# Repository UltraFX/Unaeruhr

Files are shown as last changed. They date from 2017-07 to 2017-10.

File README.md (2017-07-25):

# Unaeruhr
Code and Layout for my unary clock

The unary clock is inspired by the clock on the "Rheinturm" in Düsseldorf, Germany. 

It's three lines with each tens (10-50) and ones (1-9) to display hours, minutes and seconds.
With a button, the display can be switched to show the date (month and day).
Another button can control the time

Later, DCF77 will be added to update the time automatically.

Still Work in Progress!!

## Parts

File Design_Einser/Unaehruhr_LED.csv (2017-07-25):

ID | Bezeichner | Gehäuse | Stückzahl | Bezeichnung | Anbieter und Ref.
1 | C1 | C_0805 | 1 | 100n
2 | D1,D2,D3,D4,D5,D6,D7,D8,D9 | LED_D5.0mm-4 | 9 | LED_RCBG
3 | P1 | Pin_Header_Straight_2x07_Pitch2.54mm | 1 | INPUT
4 | P2 | Pin_Header_Straight_2x07_Pitch2.54mm | 1 | OUTPUT
5 | Q1,Q4,Q7 | SOT-23 | 3 | Q_PNP_BEC
6 | Q2,Q3,Q5,Q6,Q8,Q9,Q10,Q11,Q12 | SOT-23 | 9 | BC849
7 | R1,R2,R3,R5,R7,R8,R9,R11,R12,R13,R14,R15 | R_0805 | 12 | 10k
8 | R4,R6,R10 | R_0805 | 3 | 68
9 | U1 | SOIC-16_3.9x9.9mm_Pitch1.27mm | 1 | 74HC595
10 | REF**,REF**,REF**,REF**,REF** | 1pin | 5 | 1pin

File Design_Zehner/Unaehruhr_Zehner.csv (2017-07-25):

ID | Bezeichner | Gehäuse | Stückzahl | Bezeichnung | Anbieter und Ref.
1 | REF**,REF**,REF**,REF** | 1pin | 4 | 1pin
2 | REF**,REF**,REF**,REF**,REF**,REF**,REF**,REF**,REF**,REF**,REF**,REF**,REF** | VIA-0.3mm | 13 | VIA-0.3mm
3 | P1 | Pin_Header_Straight_2x07_Pitch2.54mm | 1 | INPUT
4 | C1 | C_0805 | 1 | 100n
5 | D1,D2,D3,D4,D5 | LED_D5.0mm-4 | 5 | LED_RCBG
6 | P2 | Pin_Header_Straight_2x07_Pitch2.54mm | 1 | OUTPUT
7 | Q1,Q4,Q7 | SOT-23 | 3 | Q_PNP_BEC
8 | Q2,Q3,Q5,Q6,Q8 | SOT-23 | 5 | BC849
9 | R1,R2,R3,R5,R7,R8,R9,R11 | R_0805 | 8 | 10k
10 | R4,R6,R10 | R_0805 | 3 | 68
11 | U1 | SOIC-16_3.9x9.9mm_Pitch1.27mm | 1 | 74HC595

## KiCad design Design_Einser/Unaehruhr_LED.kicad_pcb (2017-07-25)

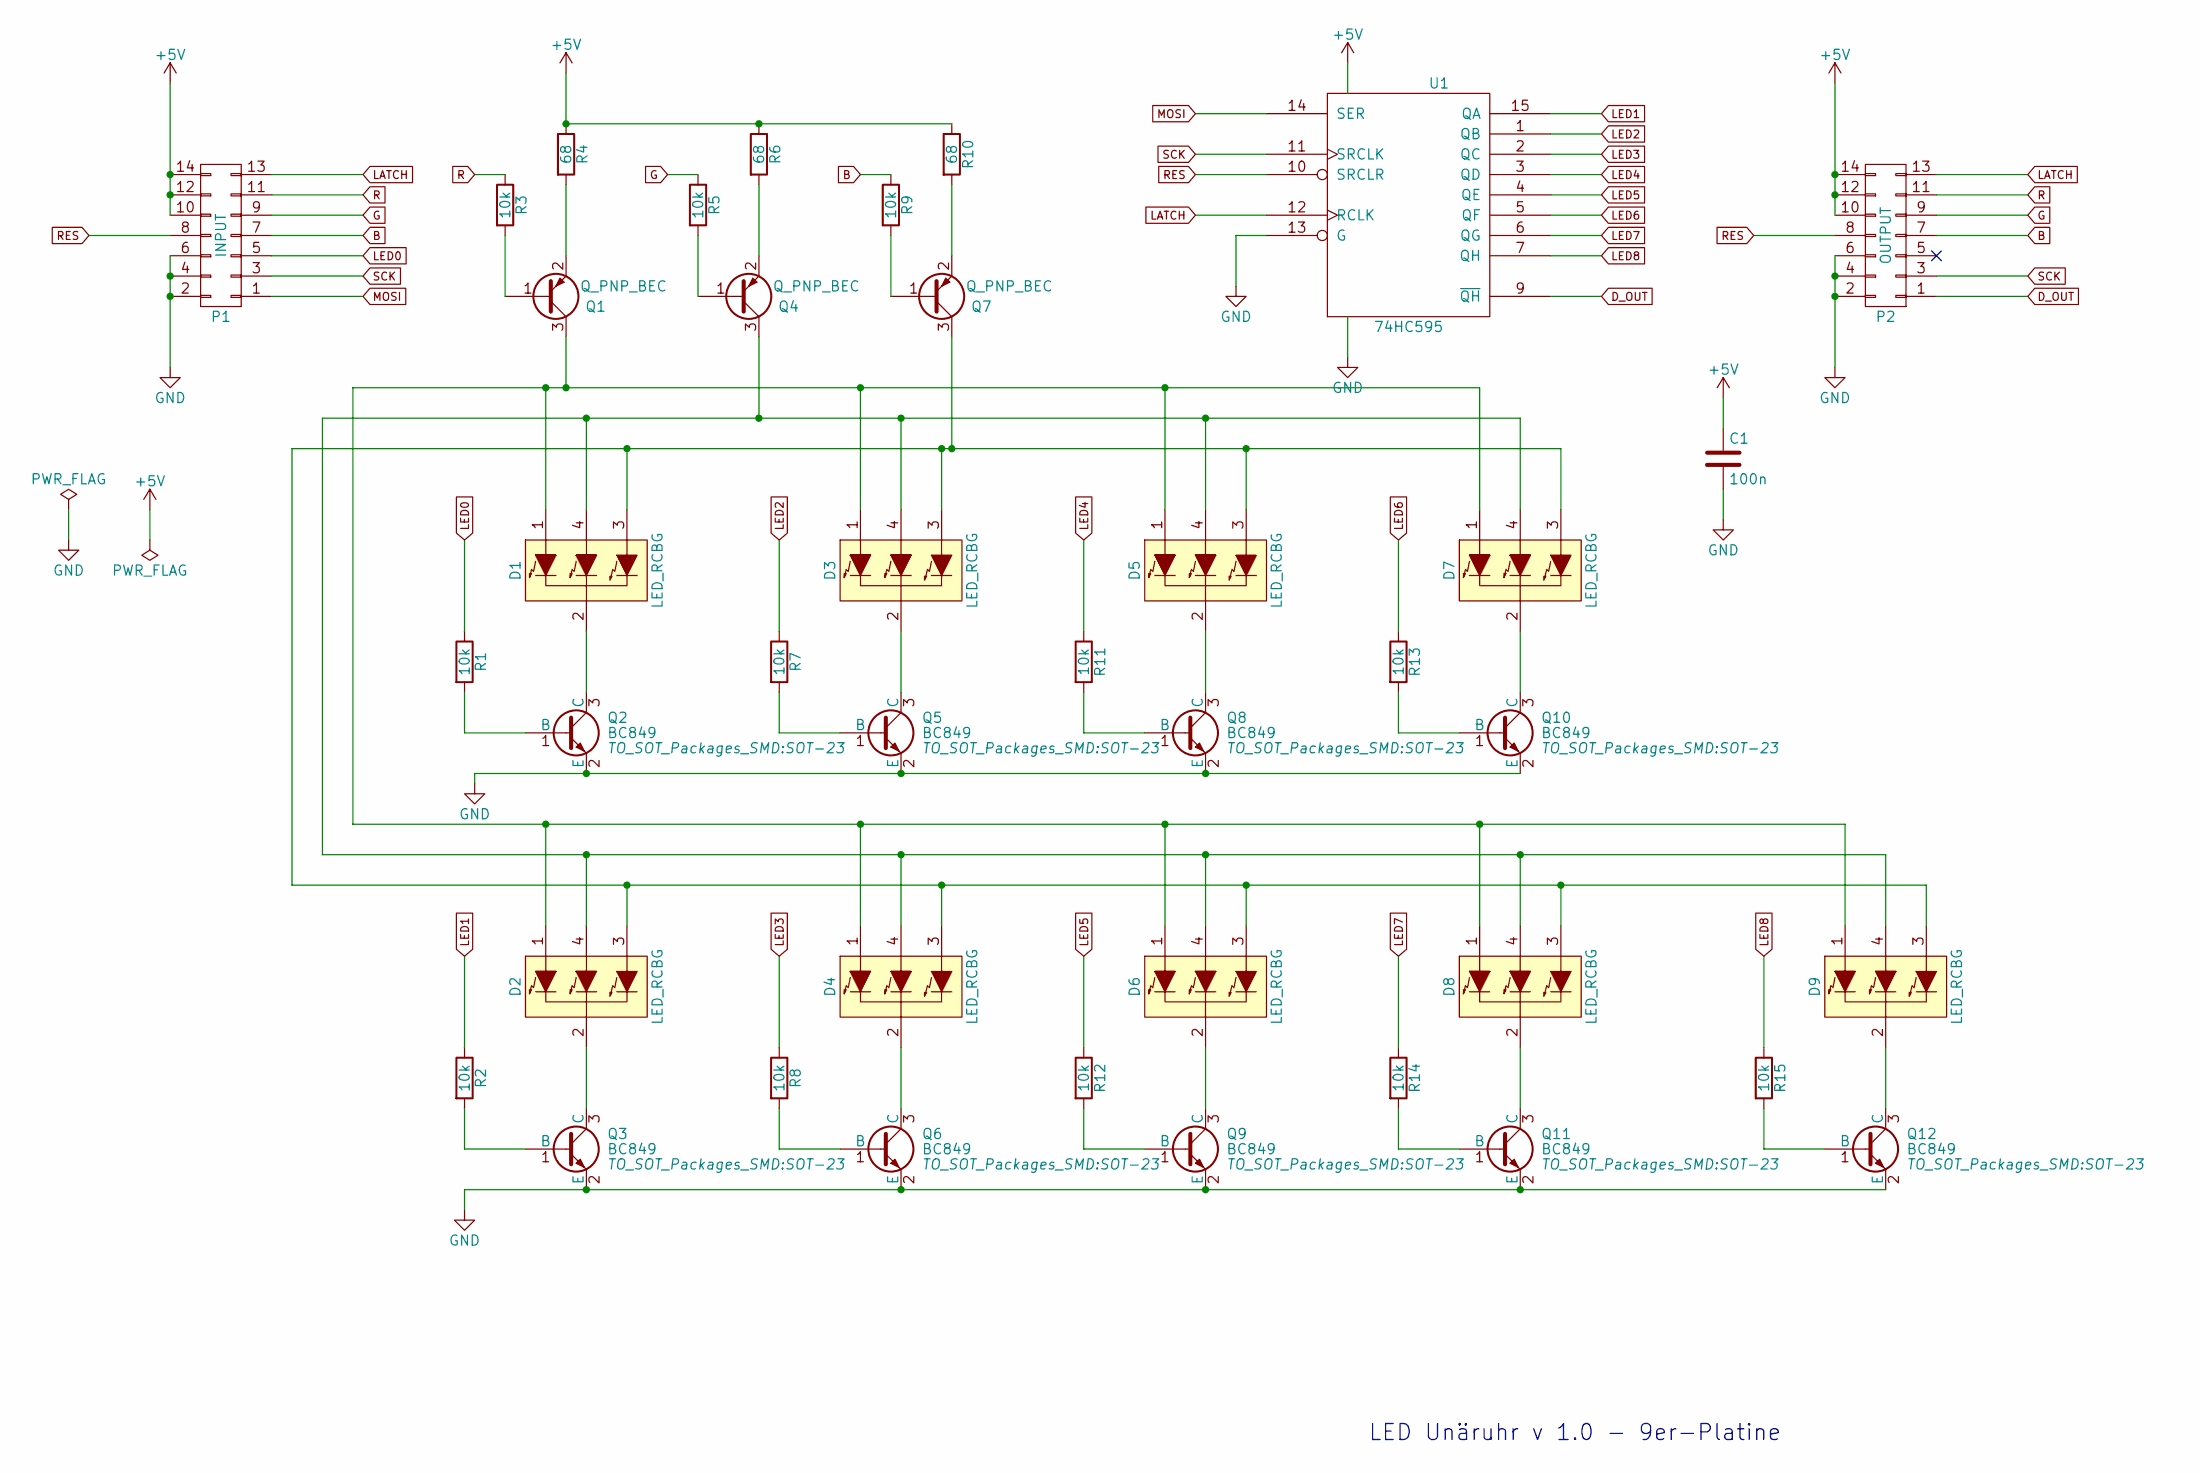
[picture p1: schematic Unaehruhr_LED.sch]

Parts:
C1: 100n; C_0805
D1, D2, D3, D4, D5, D6, D7, D8, D9: LED_RCBG; LED_D5.0mm-4
P1: INPUT; Pin_Header_Straight_2x07_Pitch2.54mm
P2: OUTPUT; Pin_Header_Straight_2x07_Pitch2.54mm
Q1, Q4, Q7: Q_PNP_BEC; SOT-23
Q2, Q3, Q5, Q6, Q8, Q9, Q10, Q11, Q12: BC849; SOT-23
R1, R2, R3, R5, R7, R8, R9, R11, R12, R13, R14, R15: 10k; R_0805
R4, R6, R10: 68; R_0805
U1: 74HC595; SOIC-16_3.9x9.9mm_Pitch1.27mm

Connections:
+5V: C1.1, P1.10, P1.12, P1.14, P2.10, P2.12, P2.14, R4.1, R6.1, R10.1, U1.16 (VCC)
B: P1.7, P2.7, R9.1
D_OUT: P2.1, U1.9 (~QH)
G: P1.9, P2.9, R5.1
GND: C1.2, P1.2, P1.4, P1.6, P2.2, P2.4, P2.6, Q2.2 (E), Q3.2 (E), Q5.2 (E), Q6.2 (E), Q8.2 (E), Q9.2 (E), Q10.2 (E), Q11.2 (E), Q12.2 (E), U1.8 (GND), U1.13 (G)
LATCH: P1.13, P2.13, U1.12 (RCLK)
LED0: P1.5, R1.1
LED1: R2.1, U1.15 (QA)
LED2: R7.1, U1.1 (QB)
LED3: R8.1, U1.2 (QC)
LED4: R11.1, U1.3 (QD)
LED5: R12.1, U1.4 (QE)
LED6: R13.1, U1.5 (QF)
LED7: R14.1, U1.6 (QG)
LED8: R15.1, U1.7 (QH)
MOSI: P1.1, U1.14 (SER)
unnamed: D1.1 (RED_ANODE), D2.1 (RED_ANODE), D3.1 (RED_ANODE), D4.1 (RED_ANODE), D5.1 (RED_ANODE), D6.1 (RED_ANODE), D7.1 (RED_ANODE), D8.1 (RED_ANODE), D9.1 (RED_ANODE), Q1.3 (C)
unnamed: D1.2 (COMMON_CATHODE), Q2.3 (C)
unnamed: D1.3 (BLUE_ANODE), D2.3 (BLUE_ANODE), D3.3 (BLUE_ANODE), D4.3 (BLUE_ANODE), D5.3 (BLUE_ANODE), D6.3 (BLUE_ANODE), D7.3 (BLUE_ANODE), D8.3 (BLUE_ANODE), D9.3 (BLUE_ANODE), Q7.3 (C)
unnamed: D1.4 (GREEN_ANODE), D2.4 (GREEN_ANODE), D3.4 (GREEN_ANODE), D4.4 (GREEN_ANODE), D5.4 (GREEN_ANODE), D6.4 (GREEN_ANODE), D7.4 (GREEN_ANODE), D8.4 (GREEN_ANODE), D9.4 (GREEN_ANODE), Q4.3 (C)
unnamed: D2.2 (COMMON_CATHODE), Q3.3 (C)
unnamed: D3.2 (COMMON_CATHODE), Q5.3 (C)
unnamed: D4.2 (COMMON_CATHODE), Q6.3 (C)
unnamed: D5.2 (COMMON_CATHODE), Q8.3 (C)
unnamed: D6.2 (COMMON_CATHODE), Q9.3 (C)
unnamed: D7.2 (COMMON_CATHODE), Q10.3 (C)
unnamed: D8.2 (COMMON_CATHODE), Q11.3 (C)
unnamed: D9.2 (COMMON_CATHODE), Q12.3 (C)
unnamed: Q1.1 (B), R3.2
unnamed: Q1.2 (E), R4.2
unnamed: Q2.1 (B), R1.2
unnamed: Q3.1 (B), R2.2
unnamed: Q4.1 (B), R5.2
unnamed: Q4.2 (E), R6.2
unnamed: Q5.1 (B), R7.2
unnamed: Q6.1 (B), R8.2
unnamed: Q7.1 (B), R9.2
unnamed: Q7.2 (E), R10.2
unnamed: Q8.1 (B), R11.2
unnamed: Q9.1 (B), R12.2
unnamed: Q10.1 (B), R13.2
unnamed: Q11.1 (B), R14.2
unnamed: Q12.1 (B), R15.2
R: P1.11, P2.11, R3.1
RES: P1.8, P2.8, U1.10 (SRCLR)
SCK: P1.3, P2.3, U1.11 (SRCLK)

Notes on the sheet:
LED Unäruhr v 1.0 - 9er-Platine

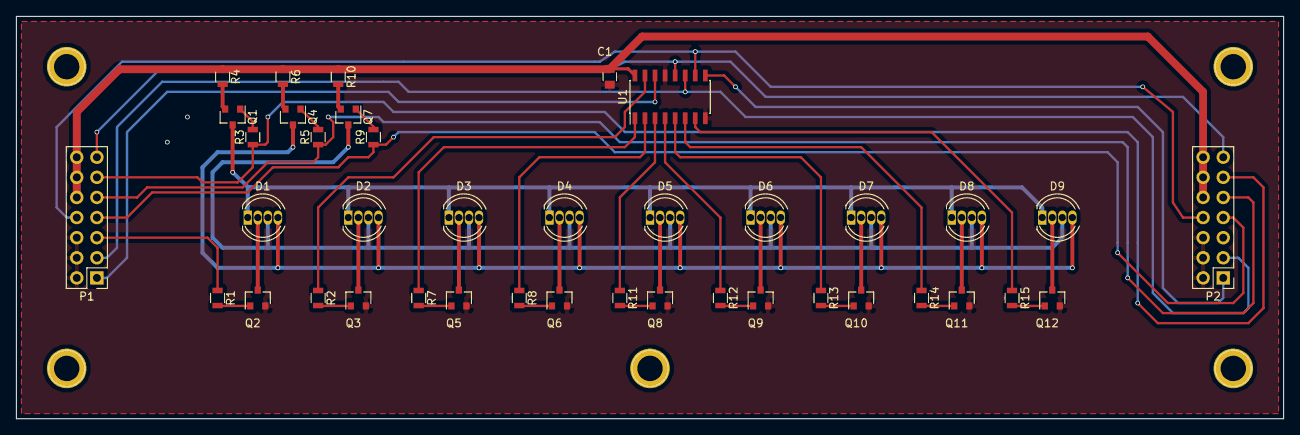
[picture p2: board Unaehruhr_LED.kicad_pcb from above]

Board: 2 copper layers, 160.0 x 50.8 mm, 40 parts (0 on the bottom side), 46 nets.

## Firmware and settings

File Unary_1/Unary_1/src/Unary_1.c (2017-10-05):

/*
 * Unary_1.c
 *
 * Created: 25.03.2015 17:16:02
 *  Author: Nicolas Dammin
 */ 


#include "main.h"

bool date = false;
uint8_t bySetType = 0;

uint8_t		g_byState = STATE_CLOCK;
uint8_t		g_byButtonFlag[3] = {0};
uint16_t	g_wButtonPressedCounter1 = 0;
uint16_t	g_wButtonPressedCounter2 = 0;
uint16_t	g_wButtonPressedCounter3 = 0;

int main(void)
{
	
	DDRD |= (1 << PD3) | (1 << PD4);
	DDRC &= ~(1 << PC2);
	PORTD = 0x00;// |= (1 << PD5);
	
	initSPI(); //initialize SPI for driving shift registers of the LEDs
	initTimer();
	initUART();
	buttons_init();
	
	if(initTWI(100000))
	{
		//Read_DS1307();
	}
	else
	{
		writeUSART("Fehler! TWI-Bitrate zu hoch!\n");
	}
	
	/*new_time[0] = 00; //Seconds
	new_time[1] = 35; //Minutes
	new_time[2] = 20; //Hours
	new_time[3] = 00; //kp
	new_time[4] = 05; //Day
	new_time[5] = 10; //Month
	new_time[6] = 17; //Year
	Write_DS1307();*/
	
	testInit();
	Start_DS1307();
	
	Read_DS1307();
	
	sprintf(buffer, "Es ist der %02d.%02d.%02d um %02d:%02d:%02d Uhr.\n", rtc_data[4], rtc_data[5], rtc_data[6], rtc_data[2], rtc_data[1], rtc_data[0]);
	Debug_send_buffer();
	
	sei();
	
	g_byState = STATE_CLOCK_ENTRY;
	
    while(1)
    {
		//dcf77_run();
		
		/* Get button states */
		buttons_handler();
		
		/*if(PINC & (1 << PC2))
		{
			PORTD |= (1 << PD3);
		}
		else
		{
			PORTD &= ~(1 << PD3);
		}*/
		
		/* Main state machine */
		switch(g_byState)
		{
		/* Init Clock */
		case STATE_CLOCK_ENTRY:
			g_byState = STATE_CLOCK;
			break;
		/* Show main clock */
		case STATE_CLOCK:
			mainProcedure();
			/* Switch to Time setup */
			if(buttons_get_first())
			{
				/* Long press: Enter time setup mode */
				if(g_wButtonPressedCounter1 >= 5)
				{
					bySetType = TYPE_TIME;
					g_byState = STATE_LOAD;
				}
				if(g_byButtonFlag[0] != 1)
				{
					count_sec = 0;
					g_byState = STATE_DATE_ENTRY;
				}
				g_byButtonFlag[0] = 1;
			}
			else
			{
				g_wButtonPressedCounter1 = 0;
				g_byButtonFlag[0] = 0;
			}

			/* Switch to Off-Setup */
			if(buttons_get_second())
			{
				if(g_wButtonPressedCounter2 >= 5)
				{
					bySetType = TYPE_OFF_TIME;
					g_byState = STATE_LOAD_START;
				}
			}
			else
			{
				g_wButtonPressedCounter2 = 0;
			}
			
			/* Switch to Off-Setup */
			if(buttons_get_third())
			{
				if(g_wButtonPressedCounter3 >= 5)
				{
					bySetType = TYPE_ON_TIME;
					g_byState = STATE_LOAD_END;
				}
			}
			else
			{
				g_wButtonPressedCounter3 = 0;
			}
			break;
		/* Init date display */	
		case STATE_DATE_ENTRY:
			g_byState = STATE_DATE;
			break;
		/* Show date */	
		case STATE_DATE:
			if(count_sec >= 10) 
			{
				g_byState = STATE_CLOCK_ENTRY;
			} 
			else
			{
				showDate();
			}
			
			if(buttons_get_first())
			{
				/* Long press: Enter time setup mode */
				if(g_wButtonPressedCounter1 >= 5)
				{
					bySetType = TYPE_TIME;
					g_byState = STATE_LOAD;
				}
				g_byButtonFlag[0] = 1;
			}
			else
			{
				g_wButtonPressedCounter1 = 0;
				g_byButtonFlag[0] = 0;
			}
			break;	
		/* Set current date and time */	
		case STATE_SET_MONTH:
			blink(STATE_SET_MONTH);
			
			if(buttons_get_first())
			{
				if(g_byButtonFlag[0] != 1)
				{
					g_byState = STATE_SET_DAY;
					g_byButtonFlag[0] = 1;	
				}
			}
			else
			{
				g_byButtonFlag[0] = 0;
			}
			break;
		case STATE_SET_DAY:
			blink(STATE_SET_DAY);
			
			if(buttons_get_first())
			{
				if(g_byButtonFlag[0] != 1)
				{
					g_byState = STATE_SET_HOURS;
					g_byButtonFlag[0] = 1;
				}
			}
			else
			{
				g_byButtonFlag[0] = 0;
			}
			break;
		case STATE_SET_HOURS:
			blink(STATE_SET_HOURS);
			
			if(buttons_get_first())
			{
				if(g_byButtonFlag[0] != 1)
				{
					g_byState = STATE_SET_MINUTES;
					g_byButtonFlag[0] = 1;
				}
			}
			else
			{
				g_byButtonFlag[0] = 0;
			}
			break;
		case STATE_SET_MINUTES:
			blink(STATE_SET_MINUTES);
			
			if(buttons_get_first())
			{
				if(g_byButtonFlag[0] != 1)
				{
					switch(bySetType)
					{
						case TYPE_TIME:
						g_byState = STATE_STORE;
						break;
						case TYPE_OFF_TIME:
						g_byState = STATE_STORE_START;
						break;
						case TYPE_ON_TIME:
						g_byState = STATE_STORE_END;
						break;
						default:
						g_byState = STATE_CLOCK_ENTRY;
						break;
					}
					g_wButtonPressedCounter1 = 0;
					g_byButtonFlag[0] = 1;
				}
			}
			else
			{
				g_byButtonFlag[0] = 0;
			}
			break;
		case STATE_STORE:
			storeTime();
			g_byState = STATE_CLOCK_ENTRY;
			break;
		/* load current time from RTC */	
		case STATE_LOAD:
			loadTime();
			g_byState = STATE_SET_MONTH;
			break;
		/* load Off-Time from EEPROM */	
        case STATE_LOAD_START:
			loadOffTime();
			g_byState = STATE_SET_HOURS;
			break;
		/* Load On-Time from EEPROM */	
		case STATE_LOAD_END:
			loadOnTime();
			g_byState = STATE_SET_HOURS;
			break;
		/* Store Off-Time to EEPROM */
		case STATE_STORE_START:
			storeOffTime();
			g_byState = STATE_CLOCK_ENTRY;
			break;
		/* Store On-Time to EEPROM */	
		case STATE_STORE_END:
			storeOnTime();
			g_byState = STATE_CLOCK_ENTRY;
			break;		
		default:
			g_byState = STATE_CLOCK_ENTRY;
		}
		
		
    }
}

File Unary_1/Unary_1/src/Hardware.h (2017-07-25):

/*
 * Hardware.h
 *
 * Created: 27.03.2015 16:55:40
 *  Author: Nicolas Dammin
 */ 


#ifndef HARDWARE_H_
#define HARDWARE_H_

#define HOUR_24 0
#define HOUR_12 1

#define DS1307_ID    0xD0        // I2C DS1307 Device Identifier
#define DS1307_ADDR  0x00        // I2C DS1307 Device Address
#define I2C_START 0
#define I2C_DATA 1
#define I2C_DATA_ACK 2
#define I2C_STOP 3
#define ACK 1
#define NACK 0


/*#define START		0x08
#define REP_START	0x10
#define AD_ACK		0x18
#define AD_NACK		0x20
#define DAT_ACK		0x28
#define DAT_NACK	0x30
#define LOSS		0x38*/

void initSPI(void);
void SPI_Send(char data);
void initTimer(void);
void initUART(void);
uint8_t initTWI (uint32_t TWI_Bitrate);

void UART_Send(char c);
void writeUSART(char *c);
void Debug_send_buffer();

unsigned char i2c_befehl(unsigned char typ, unsigned char rw);
char i2c_start(unsigned int dev_id, unsigned int dev_addr, unsigned char rw_type, unsigned char restart);
void i2c_stop(void);
char i2c_write(char data);
char i2c_read(char *data, char ack_type);

extern char buffer[100];

#endif /* HARDWARE_H_ */

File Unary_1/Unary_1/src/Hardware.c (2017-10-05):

/*
 * Hardware.c
 *
 * Created: 27.03.2015 16:55:33
 *  Author: Nicolas Dammin
 */ 

#include "main.h"
#include "LowLevel.h"

char buffer[100];

uint32_t millisecs = 0;
uint32_t timeout = 0;

void initSPI(void)
{
	DDRB = 0xFF; //Set all Pins of Port B to output
	PORTB = 0x00; //Set all outputs of B to low
	
	//PORTB |= (1<<RES_PIN); //Reset high -> NO RESET
	
	//SPSR = 0x01; //Set SPI2X
	SPCR = (1<<SPIE) | (1<<SPE) | (1<<MSTR) | (1<<SPR1) | (1<<SPI2X); //Enable SPI, set to master and Clock Rate 1/16 (1 MHz)
	
	SPDR = 0x00;
}

void SPI_Send(char data)
{
	SPDR = data; //send byte over SPI
	
	while(!(SPSR & (1<<SPIF))); //Wait untill Byte was sent
}

void initTimer(void) //Timer for 1 sec interrupts
{
	TCCR1B = (1 << WGM12) | (1 << CS12); //Select CTC mode (Compare Match) and enable Prescaler 1/256
	OCR1A = 63; //5684;						 //Compare-Match at 100ms
	
	TIMSK |= (1 << OCIE1A);
}

void initUART(void)
{
	UBRRL = 8;
	UBRRH = 0x00;
	UCSRC = (1 << URSEL) | (1 << UCSZ1) | (1 << UCSZ0);	
	
	UCSRB = (1 << RXEN) | (1 << TXEN);
}

//Zeichen über UART senden
void UART_Send(char c)
{
	while (!( UCSRA & (1 << UDRE)));
	UDR = c;
}

void writeUSART(char *c)
{
	while(*c != 0x00)
	{
		UART_Send(*c);
		c++;
	}
}

void Debug_send_buffer()
{
	int cnt = 0;
	while (buffer[cnt] != 0)
		UART_Send(buffer[cnt++]);
}

uint8_t initTWI (uint32_t TWI_Bitrate)
{
	/*
	** Set TWI bitrate
	** If bitrate is too high, then error return
	*/
	TWBR = ((F_CPU/TWI_Bitrate)-16)/2;
	if (TWBR < 11) return 0;

	return 1;
}

// START I2C Routine
unsigned char i2c_befehl(unsigned char typ, unsigned char rw) {
	switch(typ) {
		case I2C_START:  
			TWCR = (1 << TWINT) | (1 << TWSTA) | (1 << TWEN);  // Send Start Condition
			while (!(TWCR & (1 << TWINT)));
			if ((TWSR & 0xF8) != TW_START)
				return TWSR;
			break;
		case I2C_DATA:     // Send Data with No-Acknowledge
			TWCR &= ~(1 << TWEA);
			break;
		case I2C_DATA_ACK: // Send Data with Acknowledge
			TWCR |= (1 << TWEA);
			break;
		case I2C_STOP:     // Send Stop Condition
			TWCR = (1 << TWINT) | (1 << TWEN) | (1 << TWSTO);
		return 0;
	}
	
	return TWSR;
}



char i2c_start(unsigned int dev_id, unsigned int dev_addr, unsigned char rw_type, unsigned char restart)
{
	char r_val = -1;
	uint8_t		twst;

	if(restart)
	{;}
	

	r_val = i2c_befehl(I2C_START, rw_type);
	
	TWDR = (dev_id & 0xF0) | (dev_addr & 0x07) | rw_type;
	TWCR = (1 << TWINT) | (1 << TWEN);

	while (!(TWCR & (1 << TWINT)));
	
	twst = TWSR & 0xF8;
	if ((twst != TW_MT_DATA_ACK) && (twst != TW_MT_SLA_ACK)) return 0;
	
	r_val=0;

	return r_val;
}

void i2c_stop(void)
{
	// Transmit I2C Data
	TWCR = (1 << TWINT) | (1 << TWEN) | (1 << TWSTO);
}

char i2c_write(char data)
{
	char r_val = -1;
	// Send the Data to I2C Bus
	TWDR = data;
	TWCR = (1 << TWINT) | (1 << TWEN); 
	
	// Transmit I2C Data
	while (!(TWCR & (1 << TWINT)));
	// Check the TWSR status
	if((TWSR & 0xF8) != TW_MT_DATA_ACK) return r_val;
	r_val=0;

	return r_val;
}

char i2c_read(char *data,char ack_type)
{
	char r_val = -1;

	//while (!(TWCR & (1 << TWINT)));
	
	//*data = TWDR;

	if (ack_type) {
		// Read I2C Data and Send Acknowledge
		TWCR |= (1 << TWINT) | (1 << TWEN) | (1 << TWEA);
		timeout = 1000;
		while (timeout-- > 0 && !(TWCR & (1<<TWINT))); 
		*data = TWDR;
	} else {
		// Read I2C Data and Send No Acknowledge
		TWCR |= (1 << TWINT) | (1 << TWEN);
		timeout = 1000;
		while (timeout-- > 0 && !(TWCR & (1<<TWINT))); 
		*data = TWDR;
	}
	r_val=0;

	return r_val;
}

ISR(SPI_STC_vect)
{
	SPI_Interrupt();
}

ISR(TIMER1_COMPA_vect)
{
	dcf77_timer_handler();
	intMilliseconds();
	
	if(millisecs >= 1000)
	{
		intSeconds();
		millisecs = 0;
		PORTD ^= (1 << PD3);
	}
	else
		millisecs++;
}

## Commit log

2017-07-25 Folder and File structure
    Added files
    [Unaehruhr_LED.csv, Unaehruhr_LED.kicad_pcb, Unaehruhr_LED.sch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]
2017-07-27 Added Off-On-Automatism
    Not working yet
    [LowLevel.h, Unary_1.c]
2017-08-03 Bugfixes for Time-Setup
    Changelog:
    - Date/Time Setup working
    - On-/Off-Time Setup working
    - Blackout working
    Bugs:
    - Seconds not counting properly
    - Blackout only works after restarting clock
    [LowLevel.c, Unary_1.c]
2017-09-24 experiments
    Just tried out some stuff. Clock not working properly in this state
    [DS1307.c, Hardware.c, Unary_1.c]
2017-09-28 Fixes
    Still searching for the problem.. harddrive crashed
    [Hardware.c, LowLevel.c, Unary_1.c]
2017-10-05 Revert "Fixes"
    This reverts commit c3892c757fe040b767fd768806e603a6775c86c4.
    [Hardware.c, LowLevel.c, Unary_1.c]
2017-10-05 Fixed some bugs
    Clock and On-Off-Time working so far. Still have the issue that seconds overjump...
    [DS1307.c, Hardware.c, Unary_1.c]
